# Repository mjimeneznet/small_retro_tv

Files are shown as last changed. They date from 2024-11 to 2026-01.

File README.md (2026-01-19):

# 📺 Small Retro TV

This project is a modern take on the classic CRT TV, inspired by the [Simpsons TV](https://withrow.io/simpsons-tv-build-guide-waveshare) from Brandon Withrow. It plays random TV shows on a 3D-printed old CRT screen, bringing a touch of nostalgia to your living room.

**✨ Features:**
- 🎬 VLC-based video player with random playback
- 📱 Web-based WiFi configurator (no keyboard/monitor needed)
- 🌐 Video management UI (upload, delete, view videos)
- 📏 Automatic video scaling to 480px height
- 🔘 Physical button control (on/off and config mode)
- 🌐 Stream videos directly from URLs (YouTube, Vimeo, etc.) using yt-dlp
- 🔄 Automatic resume to local playback when stream ends

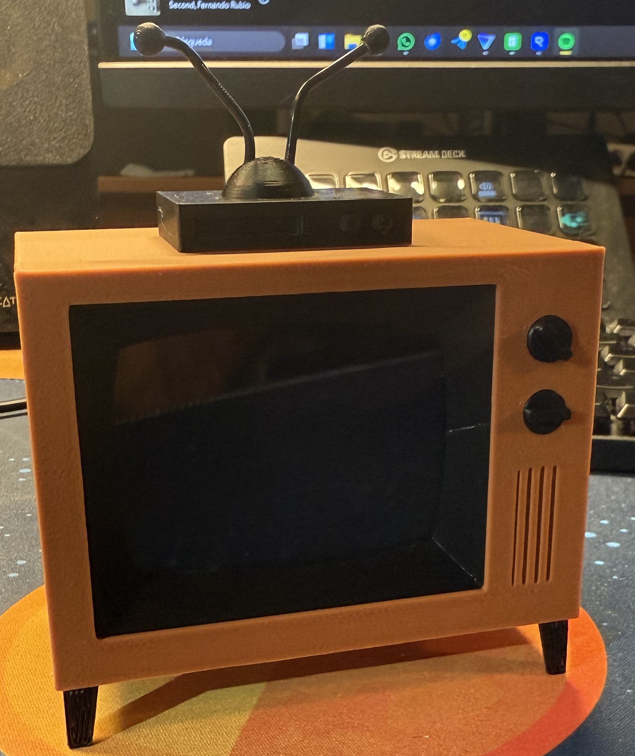
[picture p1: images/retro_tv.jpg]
Retro TV


## 🛒 Shopping List
- [Raspberry Pi Zero W](https://www.amazon.es/RASPBERRY-PI-ZERO-Ordenador-Sobremesa/dp/B07BHMRTTY)
- [Waveshare 2.8inch for Raspberry Pi 480×640 dpi](https://www.amazon.es/dp/B08LZG5G19)
- [Adafruit Mono 2.5 W Audio Amplifier](https://www.amazon.es/dp/B07YJLNVVD)
- [1.5" 4ohm 3W Audio Speaker](https://www.amazon.es/dp/B01LN8ONG4)
- [Micro USB DIP Breakout Board](https://www.amazon.es/dp/B07WC8W81F)
- [Micro USB Cable to solder](https://www.amazon.es/dp/B0CWP1MCS9)
- [1K Trim Potentiometer](https://www.amazon.es/dp/B09S3FWWW7)
- [Micro Push Button Switch](https://www.amazon.es/dp/B07BFNKLKG)
- SD Card (enough disk space to store the OS and the videos)
- Cabling

## 🛠️ Steps to Build

### 1. Hardware Assembly
Follow [the original guide](https://withrow.io/simpsons-tv-build-guide-waveshare) to solder all the pieces together.

### 2. Prepare the SD Card
- Download [Raspberry Pi OS Lite (Legacy, Debian 11 Bullseye)](https://www.raspberrypi.com/software/operating-systems/) from the official Raspberry Pi website.
- Burn the image to the SD Card using [Raspberry Pi Imager](https://www.raspberrypi.com/software/).
- Configure WiFi and SSH access before first boot (optional):
  - Enable SSH by creating an empty file named `ssh` in the boot partition
  - Create `wpa_supplicant.conf` in the boot partition with your WiFi credentials (or use the web configurator after first boot)
- Insert the SD Card into the Raspberry Pi and power it on.

### 3. Initial Setup
- SSH into your Raspberry Pi (default credentials):
  ```
  user: retrotv
  password: <your-password>
  ```
- Run `sudo raspi-config` to:
  - Expand filesystem
  - Change default password (if not set during SD card creation)
  - Set locale/timezone
- Reboot after changes.

### 4. Configure the Display
- Unzip the [28DPI-DTBO.zip](./resources/28DPI-DTBO.zip) into `/etc/overlays`. More info [here](https://www.waveshare.com/wiki/2.8inch_DPI_LCD).
- Edit `/boot/config.txt` and add the following at the end:
  ```
  gpio=0-9=a2
  gpio=12-17=a2
  gpio=20-25=a2
  dtoverlay=dpi24
  enable_dpi_lcd=1
  display_default_lcd=1
  extra_transpose_buffer=2
  dpi_group=2
  dpi_mode=87
  dpi_output_format=0x7F216
  hdmi_timings=480 0 26 16 10 640 0 25 10 15 0 0 0 60 0 32000000 1
  dtoverlay=waveshare-28dpi-3b-4b
  dtoverlay=waveshare-28dpi-3b
  dtoverlay=waveshare-28dpi-4b
  dtoverlay=waveshare-touch-28dpi
  display_rotate=3
  disable_splash=1
  ```

### 5. Software Installation
- Update the system:
  ```bash
  sudo apt update && sudo apt upgrade -y
  ```
- Install dependencies:
  ```bash
  sudo apt install -y vlc python3-flask python3-rpi.gpio python3-pip ffmpeg
  ```
- Install yt-dlp (for streaming from URLs):
  ```bash
  # Download standalone binary (recommended, no Python version conflicts)
  sudo wget https://github.com/yt-dlp/yt-dlp/releases/latest/download/yt-dlp_linux_armv7l -O /usr/local/bin/yt-dlp
  sudo chmod +x /usr/local/bin/yt-dlp
  
  # Alternative: install via apt (older version)
  # sudo apt install -y yt-dlp
  ```
- Clone this repository:
  ```bash
  cd ~
  git clone https://github.com/YOUR_USERNAME/small_retro_tv.git
  cd small_retro_tv
  ```
- Install Python dependencies:
  ```bash
  pip3 install Flask Pillow werkzeug
  ```
- Create the videos directory:
  ```bash
  mkdir -p videos
  ```

### 6. Enable Audio
- Edit `/boot/config.txt` again and add:
  ```
  dtoverlay=audremap,enable_jack,pins_18_19
  ```
- Edit `/boot/cmdline.txt` and add the following (or edit if they exist):
  ```
  console=tty3 consoleblank=0 logo.nologo quiet splash
  ```

### 7. Configure GPIO for Audio
- Create the file `/etc/rc.local` with the following content:
  ```
  #!/bin/sh -e
  # This script is executed at the end of each multiuser runlevel

  raspi-gpio set 19 op a5

  exit 0
  ```

### 8. Create the System Service
- Create the file `/etc/systemd/system/tvplayer.service` with the following [content](./resources/tvplayer.service):
  ```
  [Unit]
  Description=RetroTV Player
  After=network.target

  [Service]
  WorkingDirectory=/home/retrotv/small_retro_tv/
  ExecStart=/usr/bin/python3 /home/retrotv/small_retro_tv/retrotv.py
  Restart=always
  User=retrotv
  Group=retrotv

  [Install]
  WantedBy=multi-user.target
  ```
- Enable and start the service:
  ```bash
  sudo systemctl enable tvplayer.service
  sudo systemctl daemon-reload
  sudo systemctl start tvplayer.service
  ```

## 🎮 How to Use

### 🔘 Button Behavior

The physical button controls two modes depending on when it's pressed:

**At Startup (when connecting power):**
- **Button NOT pressed** → Enters **Configuration Mode** (WiFi setup)
- **Button pressed** → Enters **Normal Mode** (video playback)

**During Normal Mode (after startup):**
- **Button pressed** → TV screen turns ON and plays videos
- **Button released** → TV screen turns OFF (Raspberry Pi stays on)

### Normal Mode (Video Playback)

**To enter this mode:** Connect power to the Raspberry Pi **WITH the button pressed**.

Once in Normal Mode:
1. **Press and hold the button** → TV turns on and starts playing random videos
2. **Release the button** → TV turns off (but continues running in background)
3. **Access web interface** → Open `http://<raspberry-pi-ip>` in your browser to:
   - **Stream from URL** (YouTube, Vimeo, etc.):
     * Paste any video URL in the blue section
     * Click "▶️ Reproducir" to start streaming
     * Video plays immediately at max 480p quality
     * Click "⏹️ Detener Stream" to stop and return to local videos
     * Stream auto-resumes local playback when finished
   - **Upload new videos** (automatically scaled to 480px height)
   - **Delete videos** from your library
   - **View video list** with size and duration info

### Configuration Mode (WiFi Setup)

**To enter this mode:** Connect power to the Raspberry Pi **WITHOUT pressing the button**.

Once in Configuration Mode:
1. The screen will display:
   - SSID: `RetroTV`
   - Password: `RetroTV123`
   - IP address (usually `10.42.0.1`)
2. **Connect to the WiFi hotspot** from your phone/laptop
3. **Open browser** and go to `http://10.42.0.1`
4. **Scan and select your WiFi** network
5. **Enter WiFi password** and submit
6. **Press the button** → Raspberry Pi reboots and connects to your WiFi
7. Device will start in Normal Mode on next boot

## 🎉 Enjoy Your Retro TV!
Your retro TV is now ready to play random TV shows! The videos are automatically detected and reloaded every 5 seconds when changes are made through the web interface.

## 💡 Usage Examples

### Streaming from YouTube
1. Find a video on YouTube (e.g., classic cartoons, old TV shows)
2. Copy the URL: `https://www.youtube.com/watch?v=VIDEO_ID`
3. Open the web interface: `http://<raspberry-pi-ip>`
4. Paste the URL in the blue "Reproducir desde URL" section
5. Click "▶️ Reproducir"
6. The video plays immediately on your RetroTV

### Supported Streaming Sites
Thanks to yt-dlp, you can stream from 1000+ websites including:
- **YouTube** - `https://www.youtube.com/watch?v=...`
- **Vimeo** - `https://vimeo.com/...`
- **Dailymotion** - `https://www.dailymotion.com/video/...`
- **Twitch** (VODs) - `https://www.twitch.tv/videos/...`
- And many more! See [full list](https://github.com/yt-dlp/yt-dlp/blob/master/supportedsites.md)

### Managing Local Videos
1. **Upload**: Click "Subir Nuevo Video" → Select file → Automatic conversion to 480p MP4
2. **Delete**: Click 🗑️ next to any video to remove it
3. **Auto-reload**: New videos are detected within 5 seconds during playback

## 📋 Technical Details

### Video Processing
- **Automatic scaling**: Videos are automatically scaled to maximum 480px height
- **Format conversion**: All videos are converted to MP4 (H.264 baseline, AAC audio)
- **Optimization**: Videos are optimized for Raspberry Pi playback with `libx264` codec
- **Supported formats**: MP4, AVI, MKV, MOV, WebM, FLV, WMV

### URL Streaming
- **yt-dlp integration**: Extracts direct video URLs from YouTube, Vimeo, and 1000+ sites
- **Automatic quality selection**: Streams at max 480p (optimal for display)
- **No storage required**: Direct streaming without downloading
- **Smart resume**: Auto-returns to local playback when stream ends
- **Command used**: `yt-dlp -f "best[height<=480]/best" -g URL | cvlc ...`

### System Architecture
- **Python 3** with Flask web framework
- **VLC (cvlc)** for video playback with random loop mode
- **yt-dlp** for URL streaming and video extraction
- **FFmpeg/FFprobe** for video processing and metadata extraction
- **GPIO control** via RPi.GPIO library
- **Background monitoring** for automatic video list updates
- **Threaded streaming** for non-blocking URL playback

### Network Services
- **Port 80** (HTTP) - Web interface for video management (normal mode)
- **Port 80** (HTTP) - WiFi configuration interface (config mode)
- **WiFi Hotspot** - Temporary AP for initial setup (`RetroTV` / `RetroTV123`)

### Streaming Considerations
- **Network required**: Streaming needs active internet connection
- **Quality**: Automatically limited to 480p for optimal performance
- **Buffering**: May occur depending on network speed
- **Duration**: Stream URLs from YouTube expire after 6-12 hours
- **Local fallback**: System returns to local videos when stream ends

## 🔧 Troubleshooting

### Screen not working
- Verify `/boot/config.txt` has all the display settings
- Check that overlays are properly installed in `/etc/overlays`

### No audio
- Verify audio configuration in `/boot/config.txt`
- Check GPIO 19 is set correctly in `/etc/rc.local`

### Videos not playing
- Ensure videos are in the `videos/` directory
- Check VLC is installed: `which cvlc`
- Check FFmpeg is installed: `which ffmpeg`
- View logs: `sudo journalctl -u tvplayer.service -f`

### Web interface not accessible
- Check service status: `sudo systemctl status tvplayer.service`
- Verify Flask dependencies: `pip3 list | grep -i flask`
- Check network connectivity: `ip addr show`

### Streaming not working
- Verify yt-dlp is installed: `which yt-dlp`
- Test yt-dlp manually: `yt-dlp -f "best[height<=480]" -g "https://www.youtube.com/watch?v=VIDEO_ID"`
- Update yt-dlp: `sudo yt-dlp -U` (if installed via pip) or re-download binary
- Check if URL is supported: Visit [yt-dlp supported sites](https://github.com/yt-dlp/yt-dlp/blob/master/supportedsites.md)
- View streaming logs: `sudo journalctl -u tvplayer.service -f | grep -i stream`

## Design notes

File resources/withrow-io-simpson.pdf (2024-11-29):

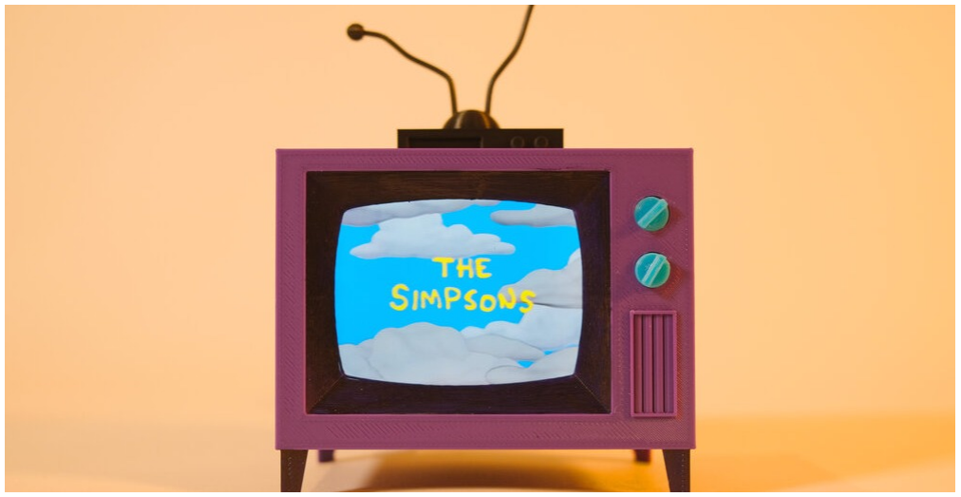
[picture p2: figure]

# Simpsons TV Build Guide - Waveshare Version

This is an variation of my original Simpsons TV build guide. (https://withrow.io/simpsons-tv-build-guide) This version uses a

different screen from the original, which is mu (https://twitter.com/theWithra)ch ea (https://github.com/buba447)sier to (http://www.linkedin.com/in/brandon-withrow-73168432) install and requires less

soldering!

What is it? A working desktop TV that plays the Simpsons on loop. This project was

born from a childhood spent in front of a TV, playing with Legos. I wanted to recreate

the ‘always on’ random nature of television, in a tiny desktop format. The videos are

always ‘playing’, even when the screen is off. Like the television in the ancient days

before the internet, you just turn it on and watch whatever it gives ya.

This guide will walk you through printing, building, and coding a small TV that will

play videos (that you provide) at random. By the end of this guide you will have your

very own tiny TV, with power and volume control. Below you will find a list of all the

parts you will need. The only thing you can’t buy is the enclosure, which needs to be

3d printed. The TV is built with a Raspberry Pi, running Linux. It might sound

intimidating, but stick with me and it can be fun!

Brandon Withrow (https://withrow.io/) | Work (https://withrow.io/work) Projects (https://withrow.io/projects) Photography (https://bytheway.photos/) About (https://withrow.io/)

The guide is aimed at all skill levels, but admittedly a few parts are more intermediate

than beginner. I believe you can do it though, so if you are a beginner, scroll slowly.

Advanced users can get their speed-read on. The entire project, including print time,

takes about 14 hours to complete.

One more thing…

Please, PLEASE do not built these and sell them, and definitely do not sell them with

copyrighted material on them!

### If you find this guide helpful and want to buy me a coffee:

DONATE HERE (https://www.paypal.com/donate?hosted_button_id=PU6T7NJ8DESC8)

# Table of Contents

- Parts List
- Tools Needed
- 3d Printing
- Video Encoding
- Hardware Setup
- Installing the OS, LCD Drivers and Audio
- Soldering the Power and Audio Circuit
- Mounting the Components
- Upgrades

# Parts List

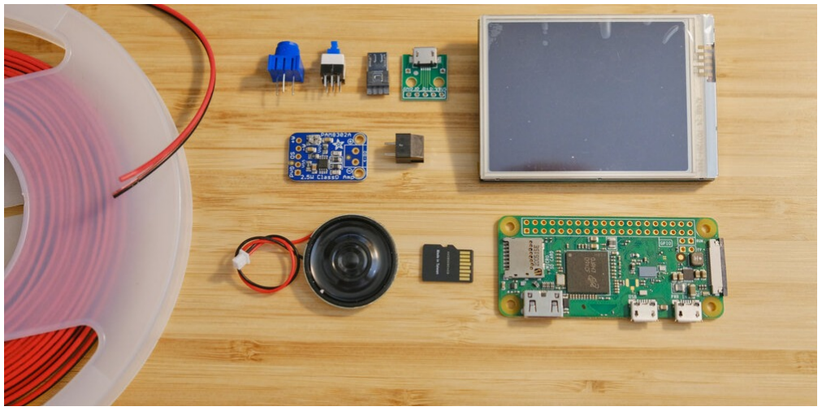
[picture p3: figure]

Please note that your Raspberry Pi should have header pins. The one pictured does not.

Here is a bill of materials that should cover the entire build process.

** Some of these are Amazon affiliate links. I earn a small commission from each

purchase, so buying through these links help me cover my time making this guide—at

no cost to you! Consider it one back scratching another, or something like that.

- Raspberry Pi Zero with Headers (https://www.adafruit.com/product/3708)
- Waveshare 2.8 640x480 Screen (https://amzn.to/3nO3w2k) - Alternative (https://www.waveshare.com/2.8inch-dpi-lcd.htm)
- Adafruit Mono 2.5 W Audio Amplifier (https://amzn.to/3gE0Ws3)
- 1.5” 4ohm 3W Audio Speaker (https://amzn.to/3koiLME)
- 64gb SanDisk SD Card (https://amzn.to/3sPehmg)
- Micro USB DIP Breakout Board (https://amzn.to/3zoBUVc)
- Micro USB Male Solder Plug (https://amzn.to/3kMflUv) - Alternative (https://amzn.to/3gNTJ8Y)
- 1K Trim Potentiometer (https://amzn.to/3yn6kG3) - Alternative (https://amzn.to/3kBQPFe) - Alternative 2 (https://amzn.to/3BsbHWh)
- Micro Push Button Switch (https://amzn.to/3zrxSLC) - Alternative (https://amzn.to/3zxJ1ec) - Alternative 2 (https://amzn.to/3BvzDbd)

- 22 Gauge Wire Black/Red Pair (https://amzn.to/3jjSOi2)

# Tools Needed

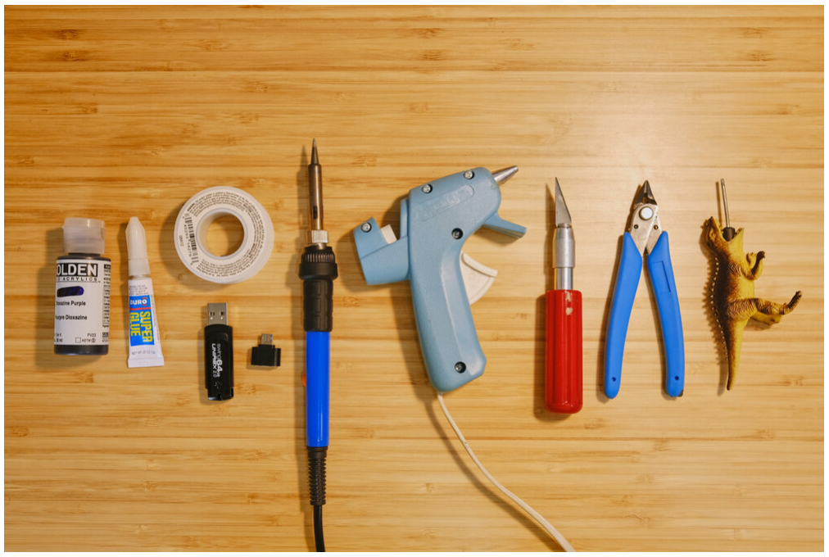
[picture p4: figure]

These are the tools needed to accomplish this project successfully. I find it’s always

best to collect the tools up front to avoid any kind of accident during the build

process.

- Soldering Iron - you will want one with a fine point tip
- Solder - I like 60/40 Rosin Core, around .032” Diameter
- Hot glue gun (the bedazzler!)
- Hobby knife - ALWAYS CUT AWAY FROM YOURSELF!
- Snips

- Flash Drive with micro-USB adapter
- Small flathead screwdriver - the dinosaur thing on the right
- Super Glue
- Dark purple acrylic paint
- Helping Hands - Not necessary, but makes soldering loads easier.

# 3d Printing the Parts

### Filament

It’s a good idea to start these prints and let them run while you setup the hardware.

All of the parts together take about 10 hours on an Ender 3 Pro. I used 3 colors of

Inland PLA+ filament: Purple for the case, light blue for the knobs, and black for the

VCR/Antenna—but have fun with it! If you print it in some fun colors, send me a pic! (https://twitter.com/thewithra)

Here are the filaments I used:

- Inland Purple PLA+
- Inland Black PLA+
- Inland Light Blue PLA+

All of the 3d printed parts needed for the build.

### Print Settings

Almost all the pieces can be printed without supports, and minimal infill. The only

exception is the front piece. Print it with a minimal support and a low infill (10%). All

pieces should be printed with their build plate orientation matching the above photo for best results. The larger parts I printed in Standard Quality (0.2mm), the smaller

parts I printer in Dynamic Quality (0.16mm). Get those pieces printing and then come

back so we can get to work on the fun stuff.

# Download the STL Files here (https://www.thingiverse.com/thing:4943159)

# Video Encoding

We should start encoding the videos before we go much further. This could take some

time so it’s best to this start early as well. The videos need to be encoded into a

specific format and put the onto a thumb drive to transfer them to the Pi later.

Basically, the videos must be encoded into the H264 format with a height of 480

pixels. Other codecs would be better/smaller, but support of codecs on the Pi is

limited with the player we are using.

Also I should mention that the videos should not be encoded directly on the Pi Zero,

unless you want to wait until the year 2050 before you can watch them. The Pi Zero is

a single-core computer with minimal processing power. It’s great for an endless

number of things, but video encoding is not one of them.

There are of course a hundred ways we could do this. I’ve written a convenient script

that will automatically encode all of the videos in a folder to the proper format. First

we need to install FFMPEG onto your computer if it is not already installed. If you

don’t know what FFMPEG is, then you probably don’t have it installed. There are

plenty of guides out there for installing FFMPEG. Check out their GitHub page for

more info. (https://github.com/adaptlearning/adapt_authoring/wiki/Installing-FFmpeg)

Once you have ffmpeg installed (you should probably restart your computer), collect

all of your videos into a folder. Download my encoding script and place it in the folder

next to your videos.

Download Video Encoding Script Here (https://github.com/buba447/simpsonstv/blob/main/videos/encode.py)

Open terminal, navigate to the folder (cd /path/to/the/folder) and run the script with:

sudo python encode.py

The script will loop through all of the video and encode them one by one. The videos

will be placed in a new sub folder called ‘encoded’. It will take some time, so be

patient! Do not close this terminal window, and keep your computer from sleeping

while it runs. When it is done you can move the ‘encoded’ folder over into your thumb

drive. Let’s move on to the next step while the videos encode. I’ll explain a little later

on how to move the videos onto the Pi.

# Hardware Setup

Please note that your Raspberry Pi should have header pins. The one pictured does not.

### Setting up the screen

In order to have TV (Television! Teacher! Mother! Secret lover…) we need to have a

screen, so let’s start there. The installation of the wave share screen is pretty easy

and solder free! Note that the Raspberry Pi should have header pins - the 40 little pins

that run along one side of the Pi. If your pi does not have header pin - don’t fret! You

can solder them on. Its a bit of a job, but you will have an endless amount of pride

once you complete it. Just read this section (https://withrow.io/simpsons-tv-build-guide#hardware-setup) from the other guide and come back after

you get the pins installed on your Pi

The Pi installed onto the screen.

To install your screen simply line the connector up with the pins on the Pi and press it

firmly down. The pins should slide nearly all the way in. That’s all there is to it!

# Installing the OS, LCD Drivers and Audio

First we need to download the operating system we intend to use. We are going to

use an older version of the Raspberry Pi OS, Buster Lite. Head over here (https://downloads.raspberrypi.org/raspbian_lite/images/raspbian_lite-2020-02-14/) and

download 2020-02-13-raspbian-buster-lite.zip. After downloading, unzip the container.

Now lets prep the SD card. There are other options for this, but the Raspberry Pi

Imager (https://www.raspberrypi.org/software/) is the easiest in my opinion. Insert the SD card into your computer and open

the Raspberry Pi Imager. Scroll down to the bottom of the list and choose ‘Use

Custom’. Find the 2020-02-13-raspbian-buster-lite.zip that you downloaded. Next select

the ‘Storage’ button. Pick your SD card from the list.

IMPORTANT: Make sure you select the SD card. If you accidentally select, say, an

external hard drive that is plugged into your computer, the next step will erase that

hard drive. Always be sure to double check. Finally select ‘Write’. It may ask for your

desktop password; this is just verifying that you want to erase and write this SD card.

After the image is written to the SD card remount (Eject and re-insert) it to your

computer. We need to make a couple quick changes before we can put it in the Pi. I

know, I’m shaking with excitement too.

We need to setup the Pi for headless boot. This way we can control / configure it from

the comfort of our desktop. Ahhh, comfort. There are several guides out there for this

bit, but in the name of being a complete guide here’s a quick rundown.

Open a text editor, I prefer Sublime. (https://www.sublimetext.com/) Create a new file and paste this bit in there:

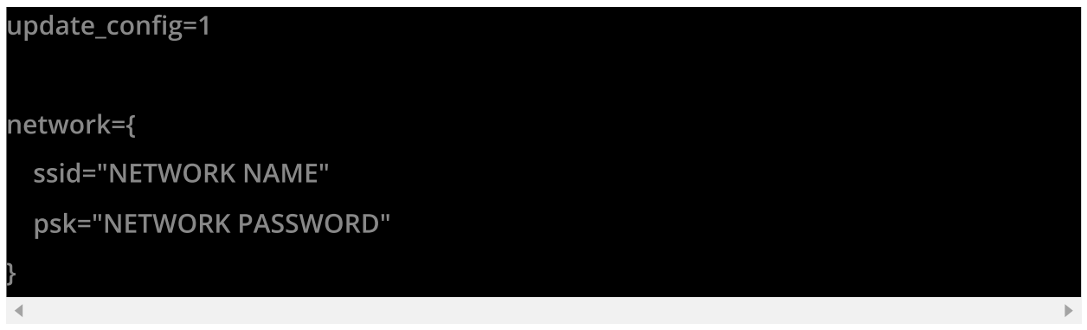
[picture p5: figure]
update_config=1; network={; ssid="NETWORK NAME"; psk="NETWORK PASSWORD"

This file will allow your Pi to connect to your wifi network when it boots. Replace

NETWORK NAME and NETWORK PASSWORD with your wifi name and password. Be

sure spelling, capitalization and spaces are correct. If you are not in the US be sure to

set the proper country code as well. Now save the file as “ wpa_supplicant.conf”

onto the root of the SD card. It should be mounted as “boot”.

Create a new blank file and save it as “ssh” with no extension onto the SD card. Thats

right, a blank file! This just enables the SSH protocol on the raspberry pi when it

boots, which allows us to connect and control it.

Next let’s install the display driver. Download the driver zip from here. (https://www.waveshare.com/wiki/File:28DPIB_DTBO.zip) Unzip it and

copy all of the files into the “overlays” folder on the SD card.

Finally open “config.txt” on the root of the SD card- be sure to open this with a text

editor like Sublime! Copy these lines onto the bottom of the file:

gpio=0-9=a2

gpio=12-17=a2

gpio=20-25=a2

dtoverlay=dpi24

enable_dpi_lcd=1

display_default_lcd=1

extra_transpose_buffer=2

dpi_group=2

dpi_mode=87

dpi_output_format=0x7F216

hdmi_timings=480 0 26 16 10 640 0 25 10 15 0 0 0 60 0 32000000 1

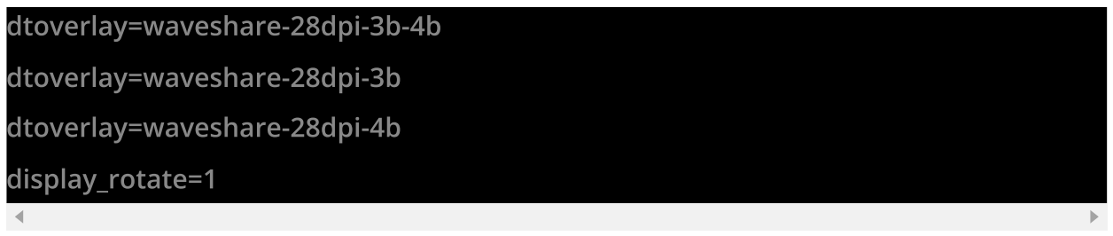
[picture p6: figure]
dtoverlay=waveshare-28dpi-3b-4b; dtoverlay=waveshare-28dpi-3b; dtoverlay=waveshare-28dpi-4b; display_rotate=1

Save and close the file. Eject the SD card from your computer.

Now you can insert the SD card into your Pi and power it up. You can use any usb

charger that supplies 2.4 amp and a micro usb cable. The screen should come on and

a bunch of text will fly past. Eventually you should see “ My IP address is

###.###.###.###” where # is a series of numbers. Write those numbers down, you

may need them. Once you see that you should be able to login from your computer.

### Software Setup

Now if everything worked correctly you should be ready to connect to your pi from

your computer. Launch terminal and type:

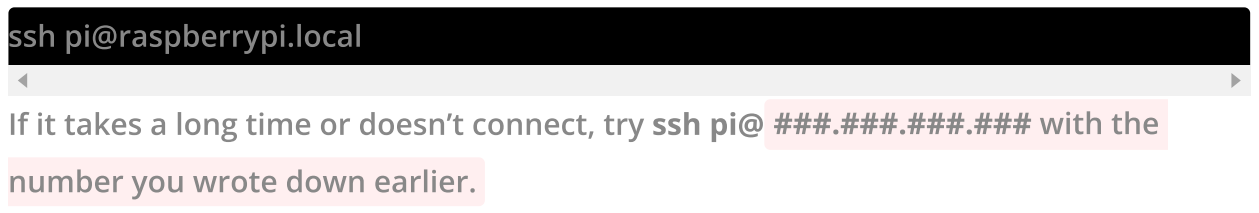
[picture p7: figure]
ssh pi@raspberrypi.local; number you wrote down earlier.

If it takes a long time or doesn’t connect, try ssh pi@ ###.###.###.### with the

The default password is raspberry. Speaking of default password, we should take this

moment to change the default password. If you don't, the King of England could just log in and start bossing your Pi around. You don’t want that do ya? DO YA? Thats what

I thought. Run the Raspberry Pi OS setup by typing:

sudo raspi-config

Change your password, save and exit. No need to reboot yet, that will happen soon

enough.

Next we need to update. Run the following command:

sudo apt-get update --allow-releaseinfo-change

These two commands might take a few minutes. During the install process it will ask

you if you want to install press Y. Press Y unless you can find the ‘Any’ key.

Now lets install usbmount. This will allow us to easily mount our USB drive when the

time comes. Run:

sudo apt-get install usbmount

Answer Y when prompted. Once it finishes we need need to edit a file to enable auto

mounting on the pi. If this is your first time typing the word ‘nano’ I should tell you

that nano is a terminal text editor that lets you edit and save files. Imagine you are

launching a full screen text editor. The up and down keys will browse through the file.

The left and right arrow keys will place a cursor on a line. To exit you hit CTRL+X. It

will then ask you if you want to save. You can type Y and then ENTER for yes and then

ENTER again to save. If you’ve never used a terminal text editor before it can be a

little disorienting at first. Just think of all the skills you are learning!

Lets edit our first file:

sudo nano /lib/systemd/system/systemd-udevd.service

Scroll down to where it says PrivateMounts=yes and change it to:

PrivateMounts=no

Next lets install raspi-gpio. This is a package that lets us control the GPIO pins on the

Raspberry Pi.

sudo apt-get install raspi-gpio

Now lets do a quick reboot before continuing.

sudo reboot -h now

Phew! Ok, we are making our way through. Take a break and marvel at how far you’ve

come. Once it has rebooted connect again over ssh.

### Enabling Audio

Now we need to configure a few things for the boot process. We need to enable the

audio output and reconfigure some GPIO pins. By default the Pi Zero does not have

any audio output, aside from HDMI. We can however enable PWM (Pulse Width

Modulation) audio and reroute the audio over to a GPIO pin (All of those tiny pins you

soldered to the screen). The TFT screen is using, well just about all, of the GPIO pins.

There are a few that are unused though. (https://www.waveshare.com/wiki/2.8inch_DPI_LCD#Interface) We have to do a few clever routings to get

audio output.

At this point I should make a quick note about the Raspberry Pi GPIO pins. The pins

use a confusing numbering system. Each pin on the board can have two different

numbers associated with them. First is the BOARD pin. These numbers count from 1

to 40 down both columns of pins. There are also the GPIO PIN numbers. Not every pin

has a GPIO number, since some of the pins aren’t used for input/output. So

confusingly the GPIO number doesn’t line up with the actual PIN number. Check

pinout.xyz for a hand quick reference.

Lets edit the boot configuration file:

sudo nano /boot/config.txt

Add the following to the bottom. This enables audio, and routes the audio to GPIO Pin

18, and 19.

Save and exit (CTRL+X, Y Enter, Enter)

Now pin 19 is free, but the screen uses pin 18 for the backlight. We need to re-

configure pin 18 during boot, or else the screen will never come on.

sudo nano /etc/rc.local

Add the following lines towards the bottom of the file, right BEFORE exit 0:

Next we need to change some boot commands to hide all of that ugly boot text, and

to disable any kind of screen blanking.

sudo nano /boot/cmdline.txt

Everything in this file is on one really long line of commands. Start scrolling right

through the line.

See where it says console=tty1? We need to change that to:

console=tty3

Continue scrolling to the end of the line. Along the way remove where it says:

fsck.repair=yes

Now at the very end of the line add:

consoleblank=0 logo.nologo quiet splash

The whole line should look similar to this. Don’t copy and paste this though, as some

thing will be different on your pi.

console=serial0,115200 console=serial0 root=PARTUUID=a0ba64cd-02 rootfstype=ext4

Save and exit (ctrl X).

Now we need to install omxplayer: a lightweight video player.

sudo apt-get install omxplayer

Now we need to install the scripts that will play videos, and make use of the power

button and knob that we will install. First, lets install git. Git is a tool that allows

downloading code from a repository.

sudo apt-get install git

Now lets install the scripts that will play videos on loop and also read the input from

the front buttons. Run these two lines:

### Moving the videos onto your Pi

It’s time to transfer the videos over! First, lets change directories:

cd ~/simpsonstv/videos

This is the directory that the video player will look for videos to play.

Lets plug in our USB drive to the spare usb port on the pi, you will need a micro USB

adapter for this. Once the USB Drive is connected lets copy all of the videos from it to

our Pi. The videos should be on the thumb drive in a folder named ‘encoded’. Run the

following command to copy the videos onto your Pi:

sudo cp -R /media/usb/encoded/. ~/simpsonstv/videos

This will probably take some time. Take a break, have a glass of water, go ponder at

the clouds.

Ok now final step! We want our video player and button control scripts to run every

time the pi boots. We will create a service for both scripts and set the Pi to run them

whenever it boots. First let’s setup the button service:

Now paste the following into the editor:

[Unit]

Description=tvbutton

After=network.target

[Service]

WorkingDirectory=/home/pi/simpsonstv/

ExecStart=/usr/bin/python /home/pi/simpsonstv/buttons.py

Restart=always

[Install]

WantedBy=multi-user.target

Now let’s setup the player service:

Paste the following into the editor and save:

[Unit]

Description=tvplayer

After=network.target

[Service]

WorkingDirectory=/home/pi/simpsonstv/

ExecStart=/usr/bin/python /home/pi/simpsonstv/player.py

Restart=always

[Install]

WantedBy=multi-user.target

Now lets set these two services to start on boot:

Now, lets shut down the pi. After it shuts down, unplug it from the power source.

sudo shutdown -h now

Phew, all this hacking has made me thirsty. Lets order a tab. Take a break, and then

let’s finish up the hardware side.

# Soldering the Power and Audio Circuit

We are going to make a few quick solders. Plug in your solder iron and warm it up.

If you have never soldered before—don’t fret—today you get to learn a new skill. I

suggest getting a good set of helping hands, (https://amzn.to/3yI4Gig) they really make it easier to solder

small bits. Check out this beginners guide to soldering (https://www.makerspaces.com/how-to-solder/) and by the end of this guide

you will be a pro.

Grab your trusty soldering iron and the rest of your components; we’ve got a little bit

of soldering left to do. It might be helpful to set this all up on the breadboard first,

but if you are feeling embiggened by the noble spirit, go ahead and solder it up. I cut

nearly all of the wires to 4-5 inch lengths. This will make the final assembly a bit

easier.

### The Audio Circuit

Lets start with the audio circuit. These are the things you will need:

- 3 wire pairs
- 1k Potentiometer
- 2.5 w mono amplifier
- 4 ohm speak

To start, let’s solder up the outgoing wires on the amplifier.

Take one black/red pair and solder the black to the ground and the red to the pad

next to the ground. These are the wires that supply the amplifier with power. Mark

them if you’d like, or take a mental snapshot. Next, solder a single wire to the Audio

In+; it should be the outermost pad. This is the wire that supplies the audio signal to

the amp (we will connect these to the Pi later). The amp should look something like

the above image.

Now we need to solder a small jumper cable between the A- and the GND of the amp

as shown above.

Now lets solder up the speaker and potentiometer. A potentiometer, or POT, is a

variable resistor with three legs. As the knob is turned, the resistance applied to the

output is increased or decreased, which results in a lower or higher current.

Essentially, it makes the signal weaker. This will control the volume going into the

speaker. We need to solder a wire to the input (the center pin) and one to the output

(the rightmost pin).

Now for the speaker. Solder a wire to one of the two speaker leads (doesn’t matter

which one). Next solder one of the wires coming from the POT to the other speaker

lead. It should look like the above image.

Finally let’s connect the speaker circuit to the amplifier. There are two output pads on

the opposite side of the amp from the input. Solder the loose speaker wire to one and

the loose wire from the POT to the other. The final audio circuit should look like this:

Before we continue, let’s make sure that the amplifier is turned all the way up. Look

on the board and you will see a small silver knob with a Phillips screwdriver marking.

Use a small screw driver to turn the knob up.

Your speaker circuit is ready!

### The Power Button and Power Cable

The power button is super easy to hook up. Solder a wire to the center pin, and

another wire to the outermost right pin. It should look something like this:

The power cable is essentially a USB adapter cable. We need our Micro USB breakout

board, a Micro USB header, and a short length of wire.

Solder a red wire to the positive, and a black wire to the ground of the breakout

board as pictured.

Now, solder the other end of the two wires—being careful to match the colors—to

the USB header. The extension cable should look like this:

### Putting it all together

Ok, let’s connect the power button to the Pi First. Above is a pinout of the Raspberry

Pi from pinout.xyz. It is oriented with the sd card facing North. Now its important to

remember that this pinout is oriented from the front side of the Raspberry Pi. We are

going to be soldering onto the back of the Raspberry Pi, so things will be flipped.

Never fear- I will illustrate where we are soldering.

First we are going to connect the two wires of the power button to GPIO 26 and the

Ground that is below it. Like so:

Now, let’s wire up the audio circuit. Take the two power wires that you marked earlier

and connect the red to the 5v+ and the black to the Ground in the upper left hand,

next to GPIO 14, like so:

Take the remaining audio input wire and connect it to GPIO 19, which is next to the

power button. Like so:

Ok. Super scary, but all of the soldering should be done! Holster that bad boy, but do

unplug it and wait for it to cool down first.

Let’s make sure everything works. Plug in your Simpsons TV and wait for it to boot.

The screen should stay off unless the screen power button is engaged. Eventually

some videos should start playing! Test that the power button toggles on and off and

that the audio knob raises and lowers the volume. To tweak the sound, turn the

volume all the way up and adjust the small POT on the amp until the audio is no

longer distorted. Phew! All the scary stuff is over. Time for the final stretch!

# Mounting the components

Now let’s put the housing together. We’re almost there! Plug in your trusty hot glue

gun. While we wait for it to heat up let’s take care of a few small things.

If you want to go the extra mile (why would you come this far to not go a little

further?), you can take some dark purple acrylic paint and paint a few details onto the

case. Paint the legs and the inlay around the front of the screen. It should be pretty

quick work; the case was designed for easy painting. If you mess up, use a wet paper

towel to wipe off the paint. You will probably want to do two coats.

### Mounting the Controls

Take the power knob, the one with the square on the back, and push it down onto

the power button. There should be a bit of resistance and a satisfying snap.

Next take the volume knob and apply a bit of super glue to the back. Press the front

of the POT into the knob. Hold it. Hold it. Hold it. Phew there we go.

Note that this is screen is different than the Waveshare. Still mount it with the Pi on the lower side.

Now, lets mount the components onto the front of the TV. Be sure to remove the

anti-scratch sticker from the front of the screen. Mmmmmhmmm, pleasing. Also

remove the power extension cable from the Pi. Place the screen face down onto the

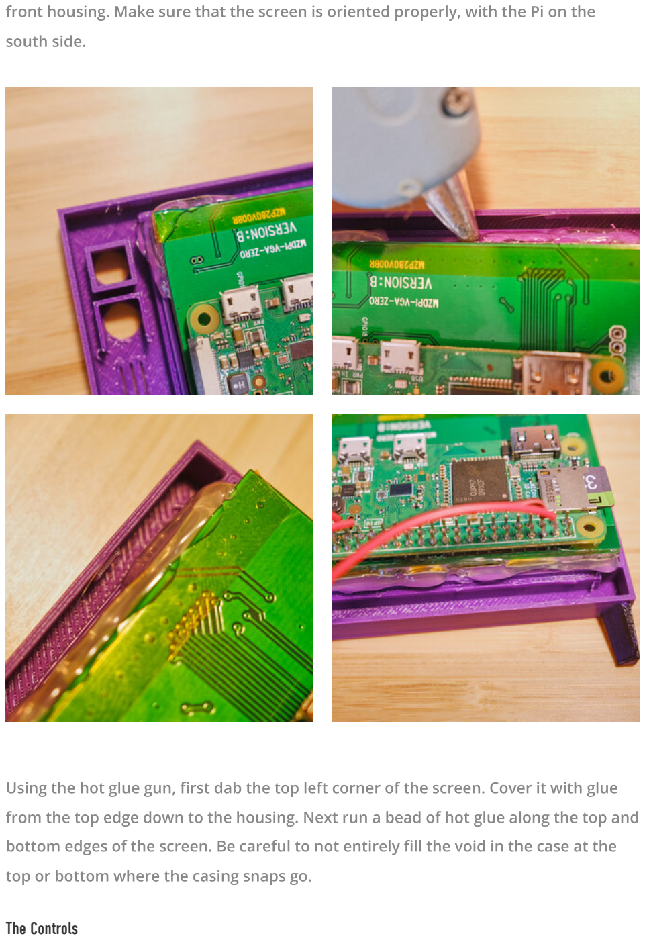
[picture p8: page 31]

front housing. Make sure that the screen is oriented properly, with the Pi on the

south side.

Using the hot glue gun, first dab the top left corner of the screen. Cover it with glue

from the top edge down to the housing. Next run a bead of hot glue along the top and

bottom edges of the screen. Be careful to not entirely fill the void in the case at the

top or bottom where the casing snaps go.

### The Controls

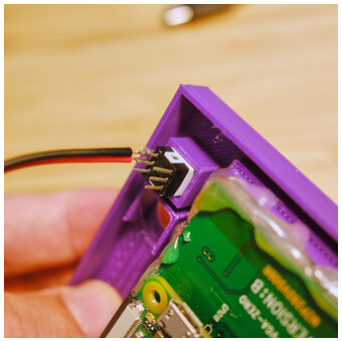
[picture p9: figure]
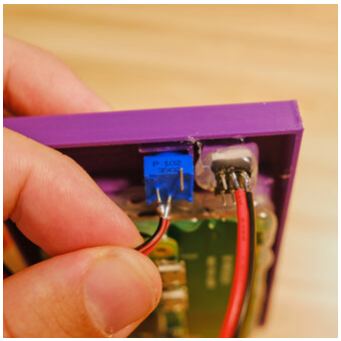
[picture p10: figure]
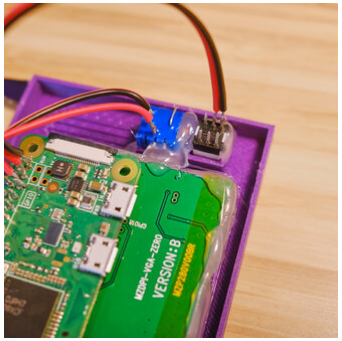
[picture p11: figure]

Now place the power button in the top knob housing. First make sure that the

button is disengaged. Press the button and release until it is at it’s tallest position.

Gently press it into the housing until the knob comes out the front of the housing. Be

careful to not press the button itself in, or it will never be able to disengage. Use

some hot glue to secure the button housing in place. Hold in place until the hot glue

dries.

Follow the same procedure for the volume knob. Don’t press it in too firmly, or the

knob won’t turn.

### TV Housing

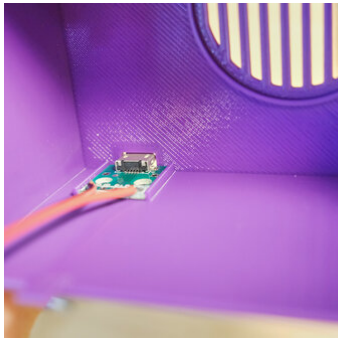
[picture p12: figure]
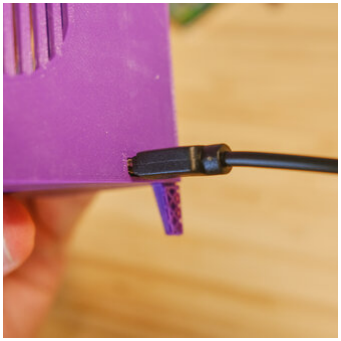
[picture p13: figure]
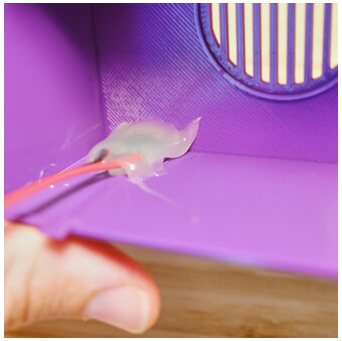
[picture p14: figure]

Ok, home stretch! Let’s mount the remaining components into the large TV housing.

Grab your usb power extension cable. Place the component board on it’s seat in the

bottom left corner of the housing. I find this next step is easier if you plug a micro usb

cable into it after placing it (leave everything unplugged from any power source). The

cable helps to hold it into place.

Use a bit of hot glue to hold it into place. Then, generously cover the whole thing,

covering the edges and connecting it to the housing. Wait for the glue to cool and turn white before moving on.

Now the speaker! Place the speaker face down on the back ring. Use hot glue to

secure it around the edges. You don’t need to glue the whole thing, just a couple of

points. Again, wait for the glue to dry and check that it’s secure before continuing.

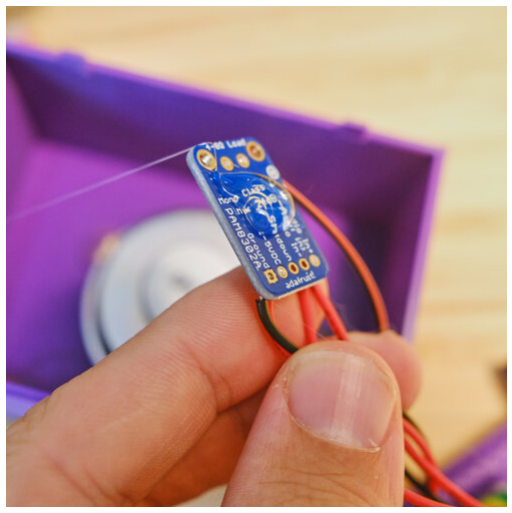
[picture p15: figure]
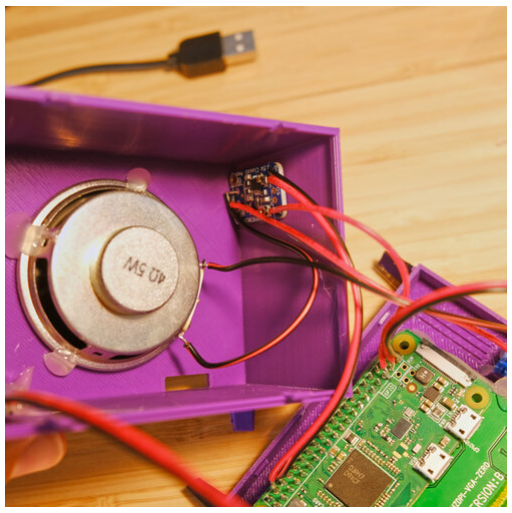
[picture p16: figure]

Finally the amplifier. For this one just put a dab of glue on the underside and press it

into the side wall of the enclosure. Easy peasy. Ok! Great work. You are done with the

hot glue gun, so holster it next to your soldering iron. Check everything and make

sure it’s secure. remove any hot glue spider webs that you find.

One more thing before we close it up. It’s time to connect the power extension cable

into the Pi’s usb power port.

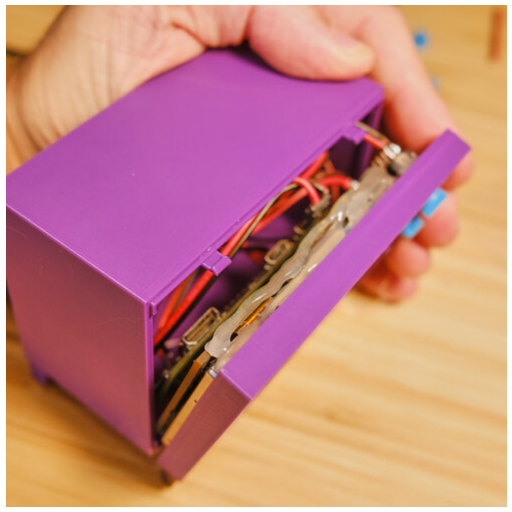
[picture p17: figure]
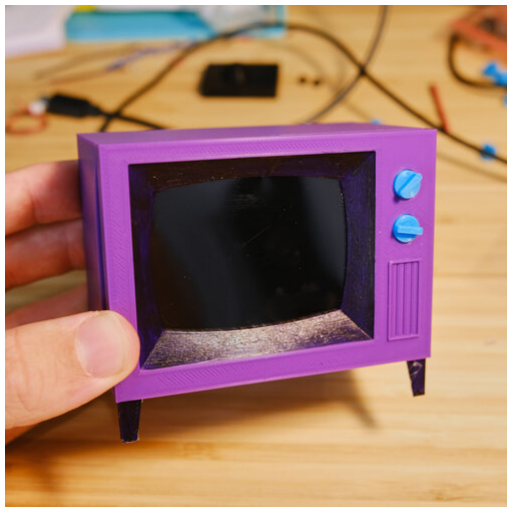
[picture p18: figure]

Time to close it up! The front of the TV snaps onto the rest of the tv using four case

snaps. Start by aligning the front onto the back. Carefully fold any wires into the

enclosure. Starting at the bottom press and snap the front onto the case. Nice!

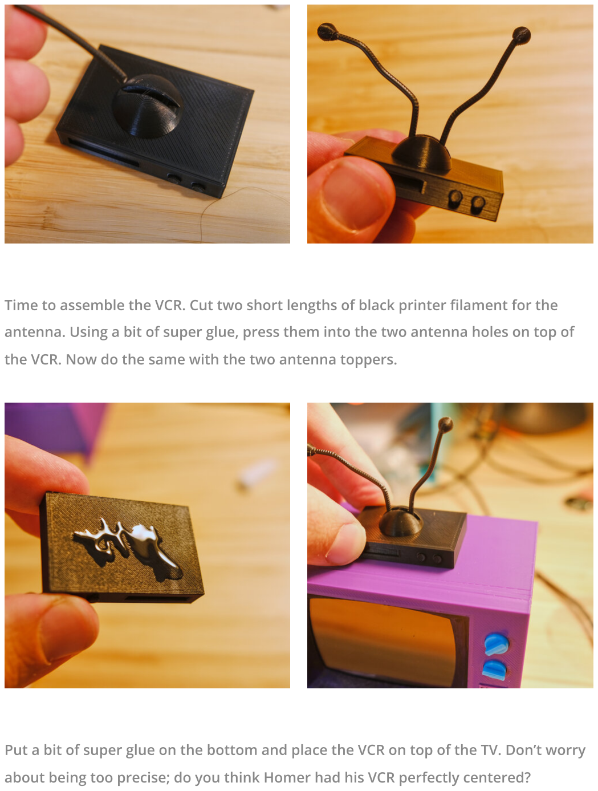
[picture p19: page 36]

Time to assemble the VCR. Cut two short lengths of black printer filament for the

antenna. Using a bit of super glue, press them into the two antenna holes on top of

the VCR. Now do the same with the two antenna toppers.

Put a bit of super glue on the bottom and place the VCR on top of the TV. Don’t worry

about being too precise; do you think Homer had his VCR perfectly centered?

Et viola! You have a tiny TV.

Congrats on making it this far—you are awesome! Tweet me (http://twitter.com/thewithra) a pic of your finished TV;

I’d love to see it. If you liked this guide and want to thank me, you can donate a few

dollars here.

DONATE HERE (https://www.paypal.com/donate?hosted_button_id=PU6T7NJ8DESC8)

# Upgrades

But wait! There’s more. Upgrades. Here are a few ideas for upgrading your Simpsons

TV.

### Faster Boot Time

Yeah, I hate waiting for my Simpsons TV to boot too. The first version was built on

PipaOS—a (http://pipaos.mitako.eu/) super light weight version of Jessie that booted almost instantly. It was

fabulous. Unfortunately, as I was writing this guide, Jessie was discontinued and is no

longer supported. There is a newer version of PipaOS built on Stretch, but I haven’t tried it yet. You should be able to follow this guide with PipaOS, but I haven’t tested it.

You might run into some errors.

### Gapless Playback / TV On-Off Graphics

This is a fun one! I’ve managed to get near gapless playback working with omxplayer

by running two instances of omxplayer and controlling them using DBUS. This is a

little advanced and takes some finessing. The other catch is that you need to know

the runtime of each video, which can be found with fprobe. This adds another layer of

complexity to the whole thing.

I was able to add TV graphics such as interstitials, on off blinks, and even a little logo

in the bottom corner using Kivy. Kivy is a lightweight graphics package for python. It

must be compiled for your os of choice, which is a more advanced topic. I find that

something like Kivy is the best for the the Pi Zero, since it is not powerful enough to

play video and also render out html. If you decide to go down this rabbit hole there’s

a lot of interesting quirks to get omxplayer and Kivy to play together. I’d be happy to

write a guide sometime if there’s enough interest.

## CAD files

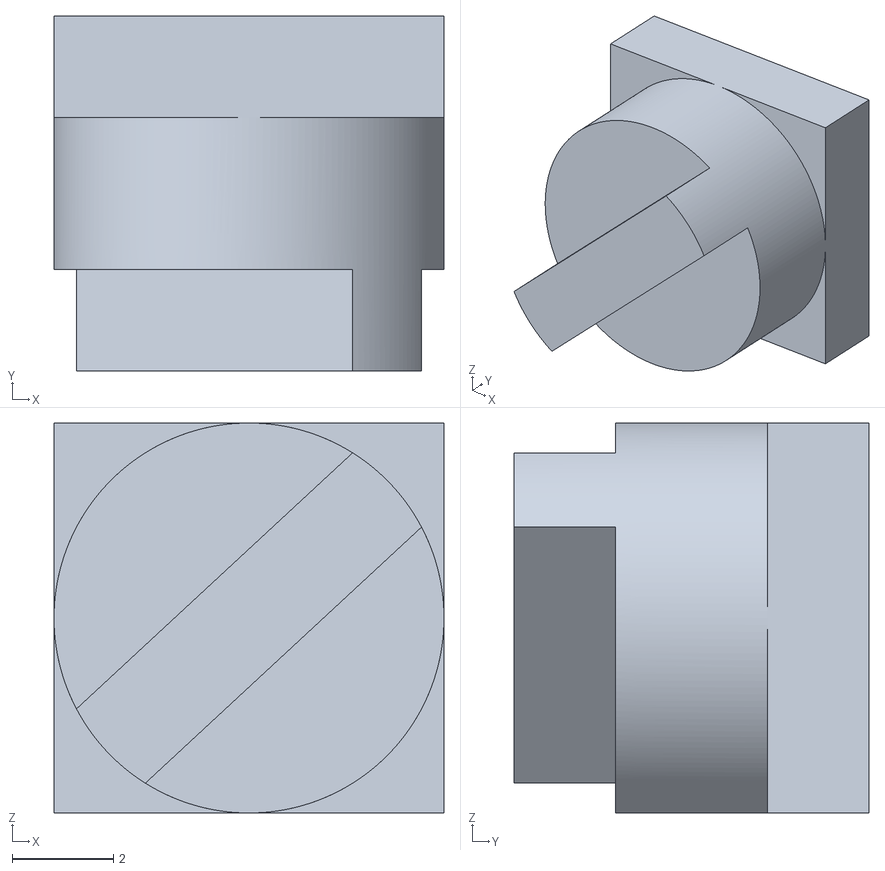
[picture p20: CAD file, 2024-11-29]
resources/3d_files/PowerButton.stl
7.70 x 7.00 x 7.70

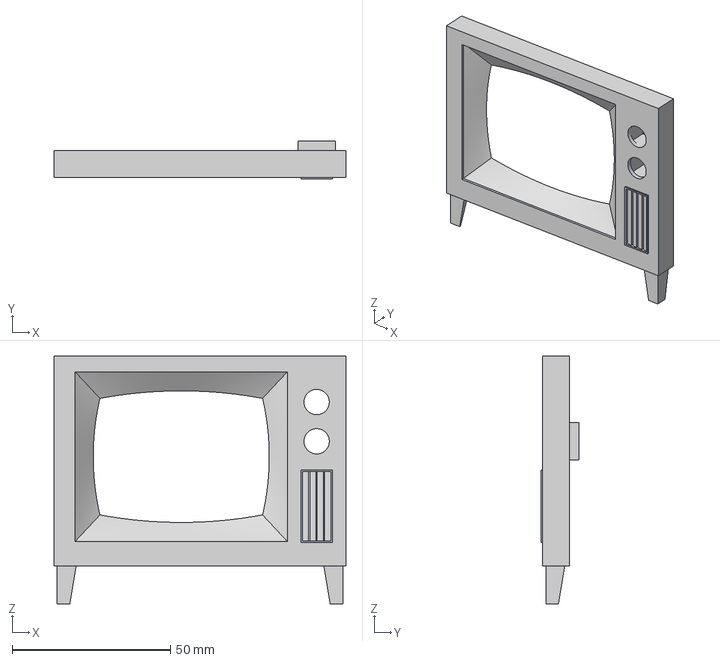
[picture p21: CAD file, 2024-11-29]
resources/3d_files/front.3mf
92.2 x 12.0 x 78.2 mm

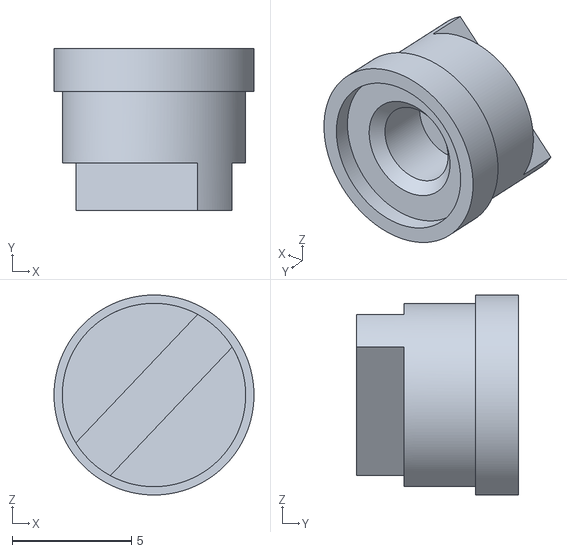
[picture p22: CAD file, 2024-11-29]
resources/3d_files/VolumeKnob.stl
8.40 x 6.80 x 8.40

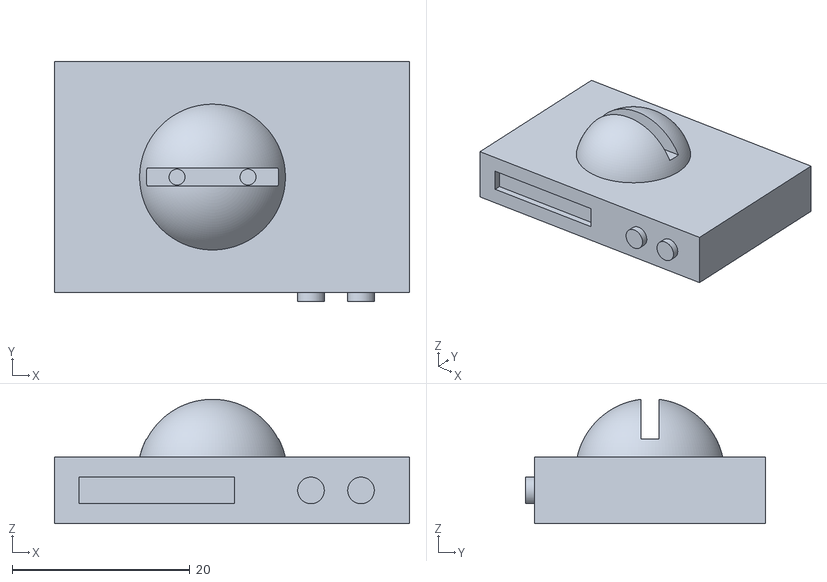
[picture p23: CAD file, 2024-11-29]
resources/3d_files/VCR.stl
40.0 x 27.0 x 14.0

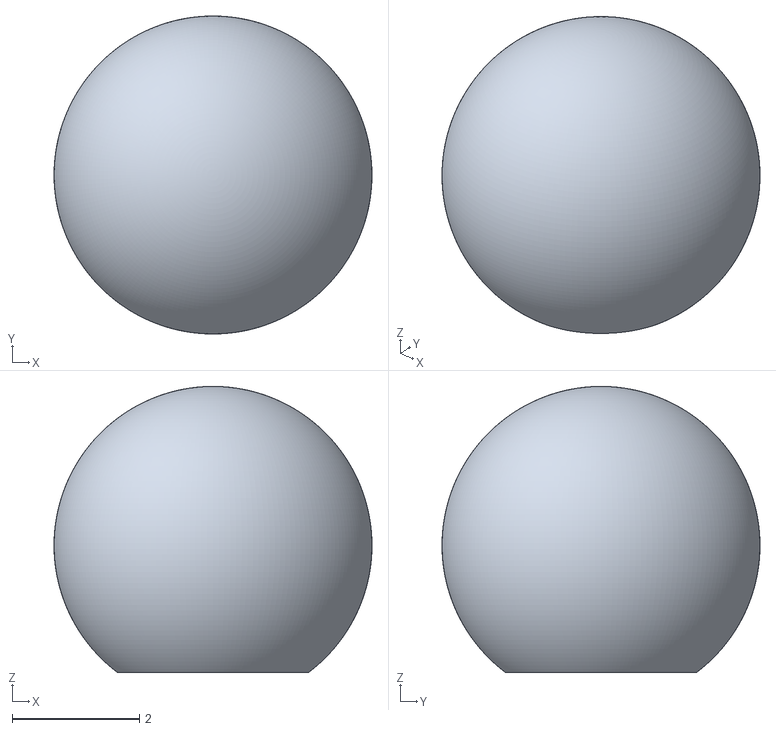
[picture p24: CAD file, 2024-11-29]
resources/3d_files/AntennaTop.stl
5.00 x 5.00 x 4.50

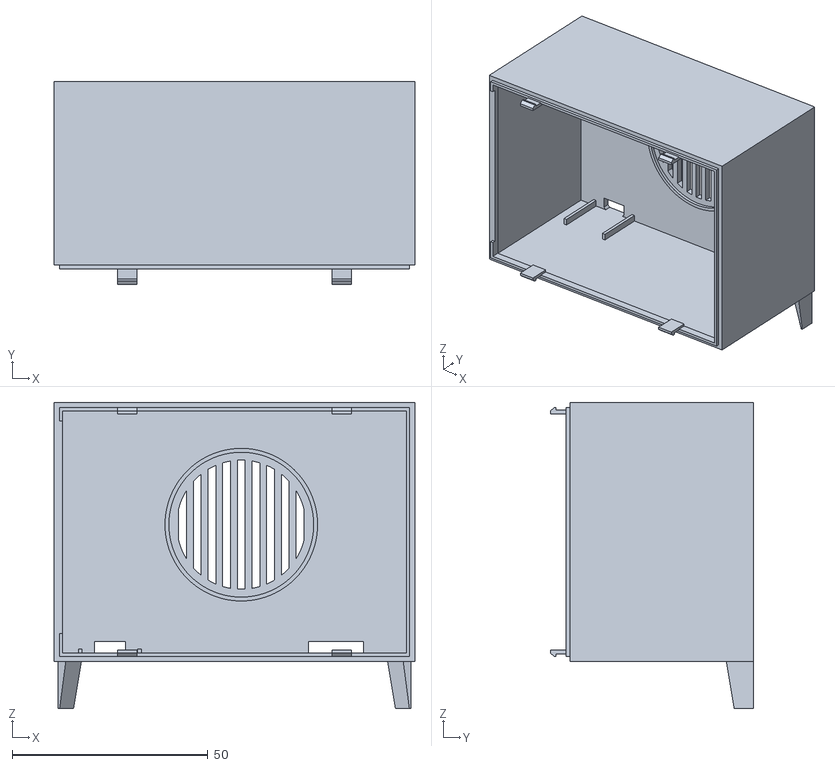
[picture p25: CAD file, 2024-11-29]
resources/3d_files/TVBody.stl
92.2 x 52.0 x 78.2

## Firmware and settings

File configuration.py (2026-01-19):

#!/usr/bin/env python3
# -*- coding: utf-8 -*-
import os
import random
import subprocess
import shlex
import threading
import time
from flask import Flask, request, jsonify, render_template_string
from PIL import Image, ImageDraw, ImageFont
from RPi import GPIO

app = Flask(__name__)

# Configuration
HOTSPOT_SSID = "RetroTV"
HOTSPOT_PASSWORD = "RetroTV123"
WPA_FILE = "/etc/wpa_supplicant/wpa_supplicant.conf"
IMAGE_SIZE = (480, 640)  # Width x Height
GPIO_PIN = 26  # Same pin as retrotv.py

# GPIO setup
GPIO.setmode(GPIO.BCM)
GPIO.setup(GPIO_PIN, GPIO.IN, pull_up_down=GPIO.PUD_UP)


def create_hotspot_info_image():
    """Generate simple centered text display"""
    
    def get_hotspot_ip():
        try:
            return subprocess.check_output(['hostname', '-I'], text=True).split()[0]
        except:
            return "169.254.0.21"

    # Create base image with black background
    img = Image.new('RGB', IMAGE_SIZE, color=(0, 0, 0))
    draw = ImageDraw.Draw(img)

    # Add subtle CRT noise effect
    for _ in range(3000):
        x = random.randint(0, IMAGE_SIZE[0]-1)
        y = random.randint(0, IMAGE_SIZE[1]-1)
        img.putpixel((x, y), (0, random.randint(20, 60), 0))

    # Load monospace font
    try:
        font = ImageFont.truetype("DejaVuSansMono.ttf", 40)
    except:
        font = ImageFont.load_default()

    # Create simple text without box decorations
    ip = get_hotspot_ip()
    text = f"""SSID: {HOTSPOT_SSID}
PASS: {HOTSPOT_PASSWORD}
IP: {ip}"""

    # Get text dimensions for centering
    bbox = draw.multiline_textbbox((0, 0), text, font=font)
    text_width = bbox[2] - bbox[0]
    text_height = bbox[3] - bbox[1]
    text_x = (IMAGE_SIZE[0] - text_width) // 2
    text_y = (IMAGE_SIZE[1] - text_height) // 2 - 110  # Moved up 2 lines

    # Draw text with subtle shadow for depth
    for dx, dy in [(2, 2)]:
        draw.multiline_text(
            (text_x + dx, text_y + dy),
            text,
            fill=(0, 100, 0),
            font=font,
            align='left',
            spacing=15
        )
    
    # Draw main text in bright green
    draw.multiline_text(
        (text_x, text_y),
        text,
        fill=(0, 255, 0),
        font=font,
        align='left',
        spacing=15
    )

    output_file = "/tmp/retrotv_config.png"
    img.save(output_file)
    return output_file


def display_image():
    """Show image using cvlc in background"""
    image_path = create_hotspot_info_image()
    return subprocess.Popen([
        "cvlc",
        "-q",
        "--fullscreen",
        "--no-osd",
        "--loop",
        "--no-video-title-show",
        image_path
    ])

def create_hotspot():
    """Create configuration hotspot with sudo"""
    subprocess.run([
        "sudo", "nmcli", "dev", "wifi", "hotspot",
        "ifname", "wlan0",
        "ssid", HOTSPOT_SSID,
        "password", HOTSPOT_PASSWORD,
        "band", "bg",
        "channel", "6"
    ], check=True)

def scan_wifi():
    """Scan WiFi networks with sudo"""
    try:
        result = subprocess.check_output(
            ["sudo", "iwlist", "wlan0", "scan"],
            stderr=subprocess.STDOUT,
            text=True
        )
        return list(set(
            line.split('"')[1]
            for line in result.split('\n')
            if "ESSID" in line
        ))
    except subprocess.CalledProcessError:
        return []

def write_wpa_config(ssid, password):
    """Securely write config with sudo privileges"""
    # Sanitize inputs
    safe_ssid = shlex.quote(ssid)
    safe_password = shlex.quote(password)

    config = f"""
network={{
    ssid={safe_ssid}
    psk={safe_password}
    key_mgmt=WPA-PSK
}}"""

    # Write using sudo tee
    subprocess.run(
        f'echo "{config}" | sudo tee -a {WPA_FILE} >/dev/null',
        shell=True,
        check=True
    )

    # Apply changes without full restart
    subprocess.run(
        ["sudo", "wpa_cli", "-i", "wlan0", "reconfigure"],
        check=True
    )

@app.route('/')
def index():
    return render_template_string("""
<!DOCTYPE html>
<html>
<head>
<style>
body {
    background: #000;
    margin: 0;
    font-family: 'Courier New', monospace;
    color: #0f0;
    overflow: hidden;
}

.crt {
    background: radial-gradient(circle, transparent 10%, rgba(0,0,0,0.8) 100%);
    position: fixed;
    width: 100%;
    height: 100%;
    pointer-events: none;
    z-index: 2;
}

.container {
    position: relative;
    width: 80%;
    margin: 2em auto;
    padding: 20px;
    background: #001100;
    border: 3px solid #0f0;
    box-shadow: 0 0 10px #0f0;
    z-index: 2;
}

h1 {
    color: #0f0;
    text-align: center;
    text-shadow: 0 0 5px #0f0;
    border-bottom: 2px solid #0f0;
    padding-bottom: 10px;
}

button, select, input {
    background: #002200;
    color: #0f0;
    border: 1px solid #0f0;
    padding: 5px 10px;
    margin: 5px;
    font-family: 'Courier New', monospace;
    font-size: 16px;
}

#networks {
    margin: 15px 0;
    position: relative;
    z-index: 4;
}

#networks select {
    width: 100%;
    padding: 8px;
    background: #001100;
    border: 2px solid #0f0;
    box-shadow: 0 0 5px #0f0;
    -webkit-appearance: none;
    -moz-appearance: none;
    appearance: none;
}

.scanlines {
    position: fixed;
    width: 100%;
    height: 100%;
    background: repeating-linear-gradient(
        0deg,
        rgba(0, 0, 0, 0.15) 0px,
        rgba(0, 0, 0, 0.15) 1px,
        transparent 1px,
        transparent 2px
    );
    pointer-events: none;
    z-index: 3;
}

.glow {
    animation: glow 2s infinite alternate;
}

@keyframes glow {
    from { text-shadow: 0 0 5px #0f0; }
    to { text-shadow: 0 0 10px #0f0, 0 0 20px #0f0; }
}

@keyframes dropdown {
    from { opacity: 0; transform: translateY(-10px); }
    to { opacity: 1; transform: translateY(0); }
}
</style>
</head>
<body>
    <div class="scanlines"></div>
    <div class="crt"></div>

    <div class="container">
        <h1 class="glow">📺 RetroTV </h1>
        <button onclick="scanNetworks()">📡 BUSCAR WIFI</button>
        <div id="networks"></div>
        <form id="wifiForm" onsubmit="return submitForm(event)">
            <input type="password" id="password" placeholder="🔑 CONTRASEÑA" required>
            <button type="submit">⚡ CONECTAR</button>
        </form>
    </div>

    <script>
    function scanNetworks() {
        fetch('/scan')
            .then(r => r.json())
            .then(nets => {
                const networksDiv = document.getElementById('networks');
                networksDiv.innerHTML = `
                    <select id="ssid" style="animation: dropdown 0.3s ease-out;">
                        ${nets.map(n => `<option>${n}</option>`).join('')}
                    </select>
                `;

                // Force z-index refresh
                networksDiv.style.display = 'none';
                networksDiv.offsetHeight; // Trigger reflow
                networksDiv.style.display = 'block';
            });
    }

    function submitForm(e) {
        e.preventDefault();
        const data = {
            ssid: document.getElementById('ssid').value,
            password: document.getElementById('password').value
        };
        fetch('/configure', {
            method: 'POST',
            headers: {'Content-Type': 'application/json'},
            body: JSON.stringify(data)
        }).then(() => {
            document.body.innerHTML = `
                <div class="container">
                    <h1 class="glow">⚙️ CONFIGURACION TERMINADA</h1>
                    <p style="text-align: center">Ya puedes salir del modo de configuracion.</p>
                </div>
            `;
        });
    }
    </script>
</body>
</html>
""")

@app.route('/scan')
def handle_scan():
    return jsonify(scan_wifi())

@app.route('/configure', methods=['POST'])
def handle_configure():
    data = request.json
    write_wpa_config(data['ssid'], data['password'])
    #subprocess.run(["sudo", "reboot"])
    return "", 200
def monitor_button_for_reboot(display_proc):
	"""Monitor GPIO button and reboot when pressed"""
	print("🔘 Monitoring button... Press to reboot")
	
	# Wait for button press
	while GPIO.input(GPIO_PIN) == GPIO.HIGH:
		time.sleep(0.1)
	
	print("✅ Button pressed! Rebooting in 2 seconds...")
	time.sleep(2)
	
	# Cleanup
	if display_proc:
		display_proc.terminate()
	GPIO.cleanup()
	
	# Turn off screen before reboot
	subprocess.call('vcgencmd display_power 0', shell=True)
	
	# Reboot
	subprocess.call(['sudo', 'reboot'])

if __name__ == "__main__":
	display_proc = None
	
	try:
		print("🌐 Creating WiFi hotspot...")
		create_hotspot()
		
		print("📺 Displaying configuration info...")
		display_proc = display_image()
		
		# Run Flask in a separate thread (daemon so it dies when main exits)
		flask_thread = threading.Thread(
			target=lambda: app.run(host='0.0.0.0', port=80, debug=False, use_reloader=False),
			daemon=True
		)
		flask_thread.start()
		
		print("🌍 Web interface available at http://10.42.0.1")
		
		# Main thread monitors button for reboot
		monitor_button_for_reboot(display_proc)
		
	except KeyboardInterrupt:
		print("\n⚠️ Interrupted by user")
	except Exception as e:
		print(f"❌ Error: {e}")
	finally:
		# Cleanup processes
		if display_proc:
			display_proc.terminate()
		GPIO.cleanup()

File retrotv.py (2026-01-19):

import os
import random
import time
import subprocess
import threading
from subprocess import Popen
from RPi import GPIO
from flask import Flask, request, render_template_string, jsonify, send_from_directory
from werkzeug.utils import secure_filename

# GPIO setup
GPIO_PIN = 26
GPIO.setmode(GPIO.BCM)
GPIO.setup(GPIO_PIN, GPIO.IN, pull_up_down=GPIO.PUD_UP)

# Configuration
CONFIG_FLAG_FILE = '/tmp/pi_config_mode'  # Temporary control file
VIDEOS_DIR = os.path.join(os.path.dirname(__file__), 'videos')
ALLOWED_EXTENSIONS = {'mp4', 'avi', 'mkv', 'mov', 'webm', 'flv', 'wmv'}

# Flask app for video management
app = Flask(__name__)
app.config['MAX_CONTENT_LENGTH'] = 500 * 1024 * 1024  # 500MB max file size

# Global state for streaming
streaming_state = {
	'active': False,
	'process': None,
	'url': None
}

def allowed_file(filename):
	"""Check if file extension is allowed"""
	return '.' in filename and filename.rsplit('.', 1)[1].lower() in ALLOWED_EXTENSIONS

def get_video_duration(filepath):
	"""Get video duration using ffprobe"""
	try:
		result = subprocess.check_output([
			'ffprobe', '-v', 'error', 
			'-show_entries', 'format=duration',
			'-of', 'default=noprint_wrappers=1:nokey=1',
			filepath
		], stderr=subprocess.STDOUT, text=True)
		
		duration_seconds = float(result.strip())
		
		# Format duration as HH:MM:SS or MM:SS
		hours = int(duration_seconds // 3600)
		minutes = int((duration_seconds % 3600) // 60)
		seconds = int(duration_seconds % 60)
		
		if hours > 0:
			return f"{hours:02d}:{minutes:02d}:{seconds:02d}"
		else:
			return f"{minutes:02d}:{seconds:02d}"
	except:
		return "N/A"

def get_video_resolution(filepath):
	"""Get video resolution using ffprobe"""
	try:
		result = subprocess.check_output([
			'ffprobe', '-v', 'error',
			'-select_streams', 'v:0',
			'-show_entries', 'stream=width,height',
			'-of', 'csv=s=x:p=0',
			filepath
		], stderr=subprocess.STDOUT, text=True)
		
		width, height = map(int, result.strip().split('x'))
		return width, height
	except:
		return None, None

def scale_video_if_needed(filepath, max_height=480):
	"""Scale video to max height if necessary, always converting to MP4"""
	try:
		width, height = get_video_resolution(filepath)
		
		if height is None:
			print(f"⚠️ Could not detect video resolution for {filepath}")
			return filepath
		
		# Always convert to .mp4 extension for consistency
		base_name = os.path.splitext(filepath)[0]
		output_filepath = base_name + '.mp4'
		
		# If resolution is OK and already MP4, no conversion needed
		if height <= max_height and filepath.endswith('.mp4'):
			print(f"✅ Video resolution OK: {width}x{height}")
			return filepath
		
		print(f"🔄 Converting video from {width}x{height} to max height {max_height}px...")
		
		# Create temporary output file
		temp_output = output_filepath + '.tmp.mp4'
		
		try:
			# Run ffmpeg to scale video with optimal settings for Raspberry Pi
			# scale=-2:480 automatically calculates width and ensures it's divisible by 2
			result = subprocess.run([
				'ffmpeg', '-i', filepath,
				'-vf', f'scale=-2:{max_height}',
				'-c:v', 'libx264',           # H.264 codec
				'-profile:v', 'baseline',     # Maximum compatibility for embedded devices
				'-level', '3.0',              # Compatible with older hardware
				'-preset', 'fast',            # Faster encoding, good for RPi
				'-crf', '23',                 # Quality (18-28, lower is better)
				'-pix_fmt', 'yuv420p',        # Universal pixel format compatibility
				'-c:a', 'aac',                # Audio codec
				'-b:a', '128k',               # Audio bitrate
				'-movflags', '+faststart',    # Optimize for streaming
				'-y',                         # Overwrite output
				temp_output
			], check=True, capture_output=True, text=True)
			
			# Remove original file
			os.remove(filepath)
			
			# Rename temp to final output
			os.rename(temp_output, output_filepath)
			
			# Get new resolution for logging
			new_width, new_height = get_video_resolution(output_filepath)
			print(f"✅ Video converted successfully to {new_width}x{new_height} → {os.path.basename(output_filepath)}")
			return output_filepath
			
		except subprocess.CalledProcessError as e:
			print(f"❌ FFmpeg error: {e.stderr}")
			# Clean up temp file if exists
			if os.path.exists(temp_output):
				os.remove(temp_output)
			# Return original filepath if conversion failed
			return filepath
		
	except Exception as e:
		print(f"❌ Error processing video: {e}")
		return filepath

def get_video_files():
	"""Get list of video files with sizes and durations"""
	videos = []
	if os.path.exists(VIDEOS_DIR):
		for filename in os.listdir(VIDEOS_DIR):
			if allowed_file(filename):
				filepath = os.path.join(VIDEOS_DIR, filename)
				size_mb = os.path.getsize(filepath) / (1024 * 1024)
				duration = get_video_duration(filepath)
				videos.append({
					'name': filename,
					'size': f"{size_mb:.2f} MB",
					'duration': duration
				})
	return sorted(videos, key=lambda x: x['name'])

def count_videos():
	"""Count current video files"""
	if not os.path.exists(VIDEOS_DIR):
		return 0
	return len([f for f in os.listdir(VIDEOS_DIR) if allowed_file(f)])

@app.route('/')
def index():
	"""Main video management interface"""
	videos = get_video_files()
	return render_template_string("""
<!DOCTYPE html>
<html>
<head>
<meta name="viewport" content="width=device-width, initial-scale=1.0">
<style>
* { box-sizing: border-box; }
body {
	background: #000;
	margin: 0;
	font-family: 'Courier New', monospace;
	color: #0f0;
	padding: 20px;
}

.container {
	max-width: 900px;
	margin: 0 auto;
	background: #001100;
	border: 3px solid #0f0;
	box-shadow: 0 0 20px #0f0;
	padding: 30px;
}

h1 {
	color: #0f0;
	text-align: center;
	text-shadow: 0 0 10px #0f0;
	border-bottom: 2px solid #0f0;
	padding-bottom: 15px;
	margin-top: 0;
	font-size: 2em;
}

.upload-section {
	background: #002200;
	border: 2px solid #0f0;
	padding: 20px;
	margin-bottom: 30px;
	border-radius: 5px;
}

input[type="file"] {
	background: #001100;
	color: #0f0;
	border: 1px solid #0f0;
	padding: 10px;
	width: 100%;
	margin: 10px 0;
	font-family: 'Courier New', monospace;
}

button {
	background: #003300;
	color: #0f0;
	border: 2px solid #0f0;
	padding: 12px 25px;
	font-family: 'Courier New', monospace;
	font-size: 16px;
	cursor: pointer;
	transition: all 0.3s;
	border-radius: 3px;
}

button:hover {
	background: #0f0;
	color: #000;
	box-shadow: 0 0 15px #0f0;
}

.delete-btn {
	background: #330000;
	border-color: #f00;
	color: #f00;
	padding: 8px 15px;
	font-size: 14px;
}

.delete-btn:hover {
	background: #f00;
	color: #000;
	box-shadow: 0 0 15px #f00;
}

.video-list {
	margin-top: 20px;
}

.video-item {
	background: #002200;
	border: 1px solid #0f0;
	padding: 15px;
	margin-bottom: 10px;
	display: flex;
	justify-content: space-between;
	align-items: center;
	border-radius: 3px;
}

.video-info {
	flex-grow: 1;
}

.video-name {
	font-weight: bold;
	color: #0f0;
	margin-bottom: 5px;
}
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

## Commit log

2024-11-29 STL for 3D printing with a remix for the switch button
    [AntennaTop.stl, PowerButton.stl, TVBody.stl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]
2025-03-05 Enhance video playback logic and screen power management
2025-03-06 Enhance configuration mode by adding screen power management and executing the configuration script directly
2026-01-19 Update button monitoring logic in configuration and retrotv modules to reflect correct button press behavior for rebooting
    [configuration.py, retrotv.py]
2026-01-19 Update README.md to reflect changes in user credentials, service configuration, and button behavior for setup modes
